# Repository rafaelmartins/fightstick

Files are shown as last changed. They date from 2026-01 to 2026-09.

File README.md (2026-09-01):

<!-- github-to-forgejo:notice:start -->
> [!IMPORTANT]
> Development has moved to [https://git.rafaelmartins.com/rafaelmartins/fightstick](https://git.rafaelmartins.com/rafaelmartins/fightstick). Please check [https://git.rafaelmartins.com/](https://git.rafaelmartins.com/) for details on how to contribute.
<!-- github-to-forgejo:notice:end -->

# fightstick

An open-source USB fight stick built around the [stm32f0-usbd-devboard](@@/p/stm32-usbd-devboards/stm32f0/), with a 3D-printable enclosure and arcade-grade controls.

For documentation please visit: https://rafaelmartins.com/p/fightstick/

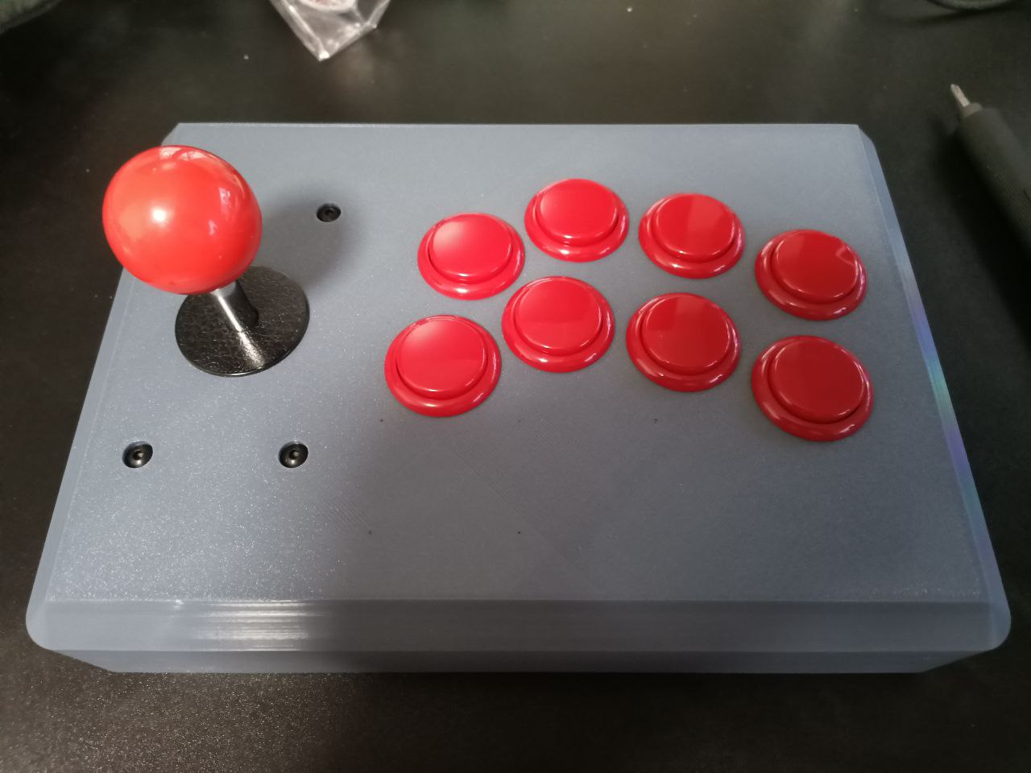
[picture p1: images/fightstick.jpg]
fightstick


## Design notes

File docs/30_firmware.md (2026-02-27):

# Firmware

The fightstick firmware is a bare-metal C application targeting the STM32F042K4 microcontroller on the [stm32f0-usbd-devboard](@@/p/stm32-usbd-devboards/stm32f0/). It implements a USB HID gamepad with a 2-axis digital joystick and 12 buttons. The firmware uses no HAL or RTOS -- it directly accesses peripheral registers via CMSIS headers and relies on the [usbd-fs-stm32](@@/p/usbd-fs-stm32/) library for USB device functionality.

## Building from source

### Prerequisites

- CMake 3.25 or later
- ARM GNU Toolchain (`arm-none-eabi`)
- Ninja (recommended) or Make

The following dependencies are fetched automatically via CMake FetchContent:

- [cmake-cmsis-stm32](@@/p/cmake-cmsis-stm32/) -- CMake build support for STM32 CMSIS-based projects
- [usbd-fs-stm32](@@/p/usbd-fs-stm32/) -- USB full-speed device library for STM32 microcontrollers

### Configure and build

```bash
cmake -B build -DCMAKE_BUILD_TYPE=Release -G Ninja
cmake --build build
```

### Output artifacts

The build produces the following in the `build/` directory:

| File | Description |
|---|---|
| `fightstick.elf` | ELF binary |
| `fightstick.elf.map` | Linker map |
| `fightstick.bin` | Raw binary |
| `fightstick.hex` | Intel HEX |
| `fightstick.dfu` | DFU with suffix (for `dfu-util`) |

### Memory layout

| Region | Start address | Size |
|---|---|---|
| Flash | `0x08000000` | 16 KB |
| RAM | `0x20000000` | 6 KB |

## Flashing

### Using USB DFU

Automated builds from the latest source are available from the [`rolling` release](https://github.com/rafaelmartins/fightstick/releases/tag/rolling).

The STM32F042K4 has a built-in USB DFU bootloader in system memory. There are two ways to enter DFU mode:

- **Empty MCU** -- a new, unprogrammed STM32F042K4 boots directly into its system memory DFU bootloader, so it is ready to flash immediately
- **Button combination** -- hold BTN09 (pin 18, B0) and BTN10 (pin 19, B1) simultaneously while powering on or resetting the device

When the firmware detects both BTN09 and BTN10 held at startup, it writes a magic value (`0xdeadbeef`) to an RTC backup register and triggers a software reset. On the subsequent boot, the firmware reads this value and jumps to the system bootloader at `0x1FFFC400`.

See the [Hardware Build Manual](@@/hardware/build-manual/) for general DFU flashing instructions using `dfu-util`.

### Using ST-Link

Flash via the provided CMake target:

```bash
cmake --build build --target fightstick-stlink-write
```

See the [Hardware Build Manual](@@/hardware/build-manual/) for general ST-Link setup and flashing instructions.

## Architecture overview

### Clock configuration

The firmware configures the system clock to use the HSI48 internal oscillator directly at 48 MHz with no PLL. Both AHB and APB buses run at 48 MHz (prescaler /1). One flash wait state is enabled as required for 48 MHz operation.

### Peripheral map

| Peripheral | Function |
|---|---|
| GPIOA PA0--PA9 | Button inputs (BTN01--BTN08, BTN11, BTN12) with internal pull-ups |
| GPIOA PA15 | Status LED output (active high) |
| GPIOB PB0--PB1 | Button inputs (BTN09, BTN10) with internal pull-ups |
| GPIOB PB3--PB6 | Joystick direction inputs (LEFT, RIGHT, DOWN, UP) with internal pull-ups |
| TIM17 | HID idle rate timer (one-pulse mode) |
| USB | Full-speed USB device peripheral |
| RTC BKP0R | Bootloader entry flag register |

See [Assembly](10_assembly.md) for physical wiring details and pin assignments.

### Main loop

The `main()` function initializes GPIO ports with pull-ups, checks for the DFU button combination, then configures the clock, idle timer, and USB peripheral. The main loop calls `usbd_task()` continuously to process USB events.

On each USB IN token for endpoint 1, the `usbd_in_cb()` callback reads all 16 GPIO inputs and constructs the HID report. The report is only sent when the input state changes or when the HID idle timer expires, reducing unnecessary USB traffic.

### Source files

| File | Purpose |
|---|---|
| `main.c` | GPIO initialization, clock setup, USB callbacks, input polling, and main loop |
| `descriptors.c` | USB device, configuration, interface, HID, and endpoint descriptors; HID report descriptor; string descriptors |
| `bootloader.c` | DFU bootloader entry logic using RTC backup register and system memory jump |
| `idle.c` | HID idle rate implementation using TIM17 in one-pulse mode |

## USB HID protocol

### Device identity

| Field | Value |
|---|---|
| USB version | 2.0 Full-Speed |
| Device class | HID (interface-level) |
| VID | `0x1d50` |
| PID | `0x619a` |
| Manufacturer | rgm.io |
| Product | fightstick |
| Serial number | STM32 internal unique ID |
| Max power | 40 mA (bus-powered) |
| HID version | 1.11 |

### Endpoints

| Direction | Type | Max packet size | Interval |
|---|---|---|---|
| EP1 IN | Interrupt | 64 bytes | 1 ms |

### HID report descriptor

The device uses the Generic Desktop / Gamepad usage page with a single input report.

| Report ID | Kind | Size | Description |
|---|---|---|---|
| 1 | Input | 2 bytes (+ 1 byte report ID) | Joystick axes and buttons |

Report layout (3 bytes total):

| Byte | Bits | Field | Values |
|---|---|---|---|
| 0 | 7:0 | Report ID | Always `0x01` |
| 1 | 1:0 | X axis | -1 (left), 0 (center), 1 (right) |
| 1 | 3:2 | Y axis | -1 (up), 0 (center), 1 (down) |
| 1 | 4 | Button 1 | 0 = released, 1 = pressed |
| 1 | 5 | Button 2 | 0 = released, 1 = pressed |
| 1 | 6 | Button 3 | 0 = released, 1 = pressed |
| 1 | 7 | Button 4 | 0 = released, 1 = pressed |
| 2 | 0 | Button 5 | 0 = released, 1 = pressed |
| 2 | 1 | Button 6 | 0 = released, 1 = pressed |
| 2 | 2 | Button 7 | 0 = released, 1 = pressed |
| 2 | 3 | Button 8 | 0 = released, 1 = pressed |
| 2 | 4 | Button 9 | 0 = released, 1 = pressed |
| 2 | 5 | Button 10 | 0 = released, 1 = pressed |
| 2 | 6 | Button 11 | 0 = released, 1 = pressed |
| 2 | 7 | Button 12 | 0 = released, 1 = pressed |

### Idle rate

The firmware implements HID Set_Idle and Get_Idle requests. The default idle rate is 500 ms (idle value 125). When the idle rate is non-zero, the firmware sends the current report periodically even if no input state has changed. When set to 0, reports are only sent on input changes.

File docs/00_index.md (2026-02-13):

---
menu: Main
---
**An open-source USB fight stick built around the [stm32f0-usbd-devboard](@@/p/stm32-usbd-devboards/stm32f0/), with a 3D-printable enclosure and arcade-grade controls.**

fightstick, assembled
The assembled fight stick, with a Sanwa JLF joystick and 30mm snap-in buttons

## Overview

fightstick is a USB gamepad designed for fighting games on Linux and MiSTer FPGA. It uses a [stm32f0-usbd-devboard](@@/p/stm32-usbd-devboards/stm32f0/) as its controller, a Sanwa JLF-TP-8YT joystick lever for directional input, eight Sanwa OBSF-30 game buttons, and four Sanwa OBSF-24 control buttons. The enclosure is fully 3D-printable.

The firmware is bare-metal C targeting the STM32F042K4 microcontroller, running at 48 MHz from the internal HSI48 oscillator. It presents itself as a standard USB HID gamepad with a 1 ms polling interval, requiring no custom drivers.

## Key highlights

- **Standard USB HID gamepad** -- no drivers required, works out of the box on Linux and MiSTer FPGA
- **1 ms polling interval** -- tested at 1.39 ms average button latency with a [Gamepad Latency Tester](https://gamepadla.com)
- **Sanwa arcade parts** -- JLF-TP-8YT joystick lever, OBSF-30 game buttons, and OBSF-24 control buttons
- **3D-printable enclosure** -- OpenSCAD parametric models for the panel and base plate
- **USB DFU firmware updates** -- enter DFU mode by pressing two buttons at startup, or flash via ST-Link
- **Bare-metal firmware** -- no HAL, no RTOS, built with [cmake-cmsis-stm32](@@/p/cmake-cmsis-stm32/) and [usbd-fs-stm32](@@/p/usbd-fs-stm32/)
- **Open source** -- hardware licensed under CERN-OHL-S-2.0, firmware under BSD-3-Clause

## How it works

The [stm32f0-usbd-devboard](@@/p/stm32-usbd-devboards/stm32f0/) reads 16 GPIO inputs (4 joystick directions and 12 buttons) using internal pull-up resistors. Each button and joystick microswitch connects its corresponding GPIO pin to ground. The firmware runs a USB HID interrupt IN endpoint that sends a 3-byte report containing a 2-axis digital joystick (X/Y values of -1, 0, or 1) and 12 button states at up to 1000 Hz. An on-board LED indicates USB enumeration status.

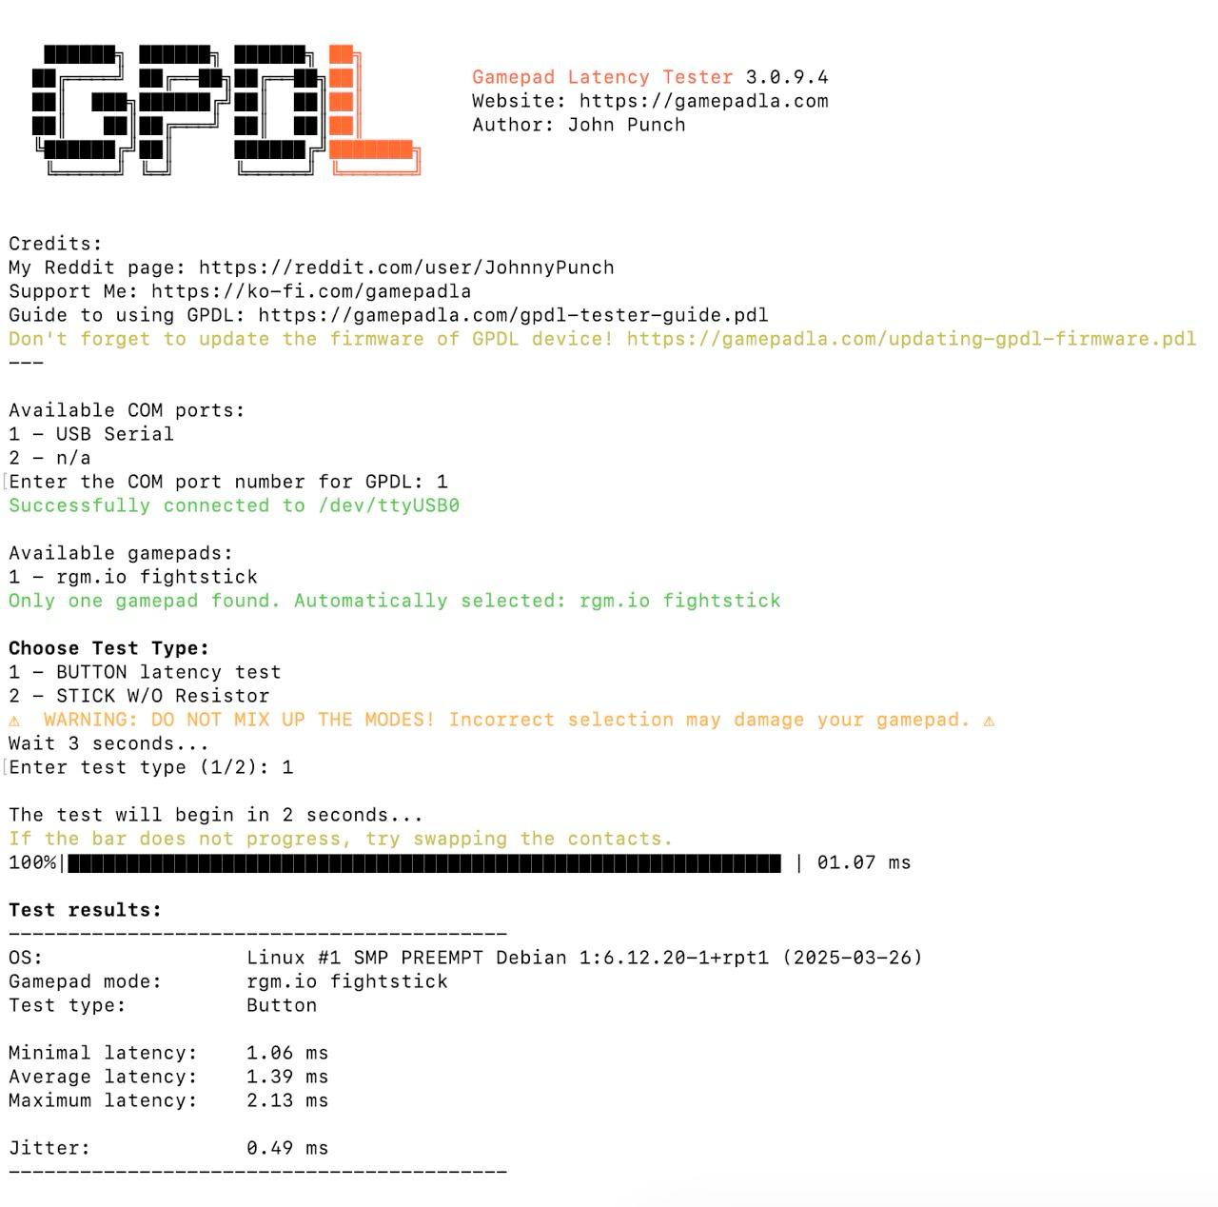
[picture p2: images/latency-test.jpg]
Gamepad Latency Tester results

Gamepad Latency Tester results: 1.06 ms minimum, 1.39 ms average, 2.13 ms maximum, 0.49 ms jitter

## Explore further

- [Assembly](10_assembly.md) -- parts list, wiring, and 3D-printed enclosure
- [Firmware](30_firmware.md) -- building, flashing, architecture, and USB HID protocol
- [Source code](https://github.com/rafaelmartins/fightstick) -- GitHub repository
- [stm32f0-usbd-devboard](@@/p/stm32-usbd-devboards/stm32f0/) -- development board documentation

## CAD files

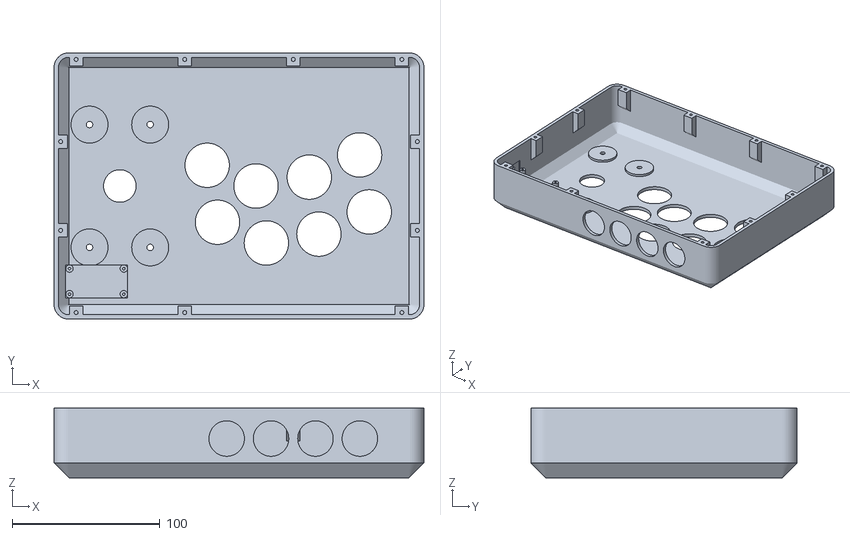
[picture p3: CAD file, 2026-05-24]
3d-models/panel.stl
250.0 x 180.0 x 47.0

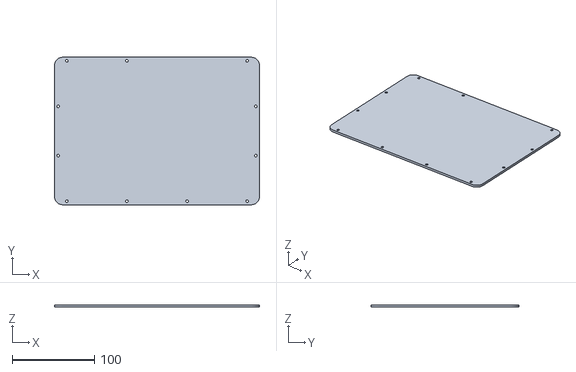
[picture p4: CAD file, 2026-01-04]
3d-models/base.stl
250.0 x 180.0 x 3.00

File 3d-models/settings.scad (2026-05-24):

/*
 * SPDX-FileCopyrightText: 2026 Rafael G. Martins <rafael@rafaelmartins.eng.br>
 * SPDX-License-Identifier: CERN-OHL-S-2.0
 */

button_control_count = 4;

length = 250;
width = 180;
height = 50;

thickness = 3;

panel_cut = 10;

button_control_d = 24;
button_control_distance = 30;
button_game_d = 30;

joystick_hole_d = 22;
joystick_width = 53;
joystick_length = 95;
joystick_width_screw_d = 41;
joystick_length_screw_d = 83;

joystick_x0 = 18 + joystick_width / 2;
joystick_y0 = width / 2;

joystick_screw_head_h = 2.8;
joystick_screw_head_d = 7.8;
joystick_screw_d = 4;
joystick_screw_base_h = 2;
joystick_screw_base_d = 25;

base_screw_padding_x = 15;
base_screw_padding_y = 60;
base_screw_dim = 9;
base_screw_d = 3;
base_screw_h = 16;
base_length_screw_distance = (length - 30) / 3;
base_width_screw_distance = (width - 120);

led_d = 3.2;
usb_height = 4.4;
usb_width = 8.2;

usb_cutout_padding_x = 1.6;
usb_cutout_padding_y = 12;
usb_cutout_padding_z = 18;
usb_cutout_thickness = thickness - 1.6;
usb_cutout_length = 28;
usb_cutout_height = 14;

devboard_pcb_height = 1.6;
devboard_width = 23.114;
devboard_length = 51.943;
devboard_screw_padding_front_x = 7.874;
devboard_screw_padding_back_x = 7.366;
devboard_screw_padding_y = 2.921;
devboard_screw_distance_y = 2 * 8.636;
devboard_screw_distance_x = 36.703;
devboard_screw_base_d = 5;
devboard_screw_base_h = height / 2;
devboard_screw_d = 2;
devboard_distance_usb = devboard_screw_padding_y + 8.636;
devboard_distance_led = devboard_screw_padding_y + 1.524;
devboard_pcb_padding_x = 2.6;
devboard_pcb_padding_y = 14;
devboard_base_distance_x = panel_cut - 2.1;
devboard_base_distance_y = usb_cutout_padding_y + 2.4;
devboard_base_length = devboard_screw_distance_x + 5.1;
devboard_base_width = usb_cutout_length - 5.7;
devboard_base_height = usb_cutout_padding_z - thickness;

$fn=50;

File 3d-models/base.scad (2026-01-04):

/*
 * SPDX-FileCopyrightText: 2026 Rafael G. Martins <rafael@rafaelmartins.eng.br>
 * SPDX-License-Identifier: CERN-OHL-S-2.0
 */

include <settings.scad>


translate([0, width, thickness]) rotate([180, 0, 0]) difference() {
    minkowski() {
        translate([panel_cut, panel_cut, 0])
            cube([length - 2 * panel_cut, width - 2 * panel_cut, thickness - 1]);
        cylinder(r=panel_cut, h=1);
    }

    for (i=[0:3])
        if (i != 2)
            translate([base_screw_padding_x + i * base_length_screw_distance, base_screw_dim / 2, 0])
                cylinder(h=thickness, d=base_screw_d * 1.1);

    for (i=[0:3])
        translate([base_screw_padding_x + i * base_length_screw_distance, width - base_screw_dim / 2, 0])
            cylinder(h=thickness, d=base_screw_d * 1.1);

    for (i=[0:1])
         translate([base_screw_dim / 2, base_screw_padding_y + i * base_width_screw_distance, 0])
             cylinder(h=thickness, d=base_screw_d * 1.1);

    for (i=[0:1])
         translate([length - base_screw_dim / 2, base_screw_padding_y + i * base_width_screw_distance, 0])
             cylinder(h=thickness, d=base_screw_d * 1.1);
}

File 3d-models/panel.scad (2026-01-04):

/*
 * SPDX-FileCopyrightText: 2026 Rafael G. Martins <rafael@rafaelmartins.eng.br>
 * SPDX-License-Identifier: CERN-OHL-S-2.0
 */

include <lib/screw-base.scad>
include <settings.scad>


difference() {
    union() {
        difference() {
            minkowski() {
                translate([panel_cut, panel_cut, 0])
                    cube([length - 2 * panel_cut, width - 2 * panel_cut, height - thickness - panel_cut]);
                cylinder(r1=0, r2=panel_cut, h=panel_cut);
            }

            translate([0, 0, thickness])
                minkowski() {
                    translate([panel_cut, panel_cut, 0])
                        cube([length - 2 * panel_cut, width - 2 * panel_cut, height - thickness - panel_cut]);
                    cylinder(r1=0, r2=panel_cut - thickness, h=panel_cut - thickness);
                }
        }

        translate([joystick_x0, joystick_y0, 0]) {
            translate([-joystick_width_screw_d / 2, -joystick_length_screw_d / 2, 0])
                cylinder(h=thickness + joystick_screw_base_h, d=joystick_screw_base_d);
            translate([-joystick_width_screw_d / 2, joystick_length_screw_d / 2, 0])
                cylinder(h=thickness + joystick_screw_base_h, d=joystick_screw_base_d);
            translate([joystick_width_screw_d / 2, -joystick_length_screw_d / 2, 0])
                cylinder(h=thickness + joystick_screw_base_h, d=joystick_screw_base_d);
            translate([joystick_width_screw_d / 2, joystick_length_screw_d / 2, 0])
                cylinder(h=thickness + joystick_screw_base_h, d=joystick_screw_base_d);
        }

        for (i=[0:3])
            if (i != 2)
                translate([base_screw_padding_x + i * base_length_screw_distance, base_screw_dim / 2, height - thickness])
                    rotate([0, 0, 90])
                        screw_base(dim=base_screw_dim, screw_d=base_screw_d, screw_h=base_screw_h);

        for (i=[0:3])
            translate([base_screw_padding_x + i * base_length_screw_distance, width - base_screw_dim / 2, height - thickness])
                rotate([0, 0, -90])
                    screw_base(dim=base_screw_dim, screw_d=base_screw_d, screw_h=base_screw_h);

        for (i=[0:1])
             translate([base_screw_dim / 2, base_screw_padding_y + i * base_width_screw_distance, height - thickness])
                 screw_base(dim=base_screw_dim, screw_d=base_screw_d, screw_h=base_screw_h);

        for (i=[0:1])
             translate([length - base_screw_dim / 2, base_screw_padding_y + i * base_width_screw_distance, height - thickness])
                 rotate([0, 0, 180])
                     screw_base(dim=base_screw_dim, screw_d=base_screw_d, screw_h=base_screw_h);

        for (i=[0:1])
            for (j=[0:1])
                translate([devboard_pcb_padding_x + devboard_screw_padding_front_x + i * devboard_screw_distance_x,
                           devboard_pcb_padding_y + devboard_screw_padding_y + j * devboard_screw_distance_y,
                           thickness])
                    cylinder(h=devboard_screw_base_h, d=devboard_screw_base_d);

        translate([devboard_base_distance_x, devboard_base_distance_y, thickness])
            cube([devboard_base_length, devboard_base_width, devboard_base_height]);
    }

    for (i=[0:1])
        for (j=[0:1])
            translate([devboard_pcb_padding_x + devboard_screw_padding_front_x + i * devboard_screw_distance_x,
                       devboard_pcb_padding_y + devboard_screw_padding_y + j * devboard_screw_distance_y,
                       thickness])
                cylinder(h=devboard_screw_base_h, d=devboard_screw_d * 0.9);

    translate([0, devboard_pcb_padding_y + devboard_width - devboard_distance_usb - usb_width / 2,
               thickness + devboard_screw_base_h - usb_height + 0.2])
        cube([thickness, usb_width, usb_height]);

    translate([0, devboard_pcb_padding_y + devboard_width - devboard_distance_led,
               thickness + devboard_screw_base_h - led_d / 2])
        rotate([-90, 0, -90])
            cylinder(h=thickness, d=led_d);

    translate([base_screw_padding_x + base_length_screw_distance, 0, 3 + (height - thickness) / 2])
        for (i=[0:button_control_count - 1])
            translate([(2 * base_length_screw_distance - (button_control_count - 1) * button_control_distance) / 2 +
                       i * button_control_distance, 0, 0])
                rotate([-90, 0, 0])
                    cylinder(h=thickness + 0.1, d=button_control_d);

    translate([joystick_x0, joystick_y0, 0]) {
        cylinder(h=thickness, d=joystick_hole_d);

        translate([-joystick_width_screw_d / 2, -joystick_length_screw_d / 2, 0]) {
            cylinder(h=joystick_screw_head_h, d=joystick_screw_head_d);
            cylinder(h=thickness + joystick_screw_base_h, d=joystick_screw_d * 1.1);
        }
        translate([-joystick_width_screw_d / 2, joystick_length_screw_d / 2, 0]) {
            cylinder(h=joystick_screw_head_h, d=joystick_screw_head_d);
            cylinder(h=thickness + joystick_screw_base_h, d=joystick_screw_d * 1.1);
        }
        translate([joystick_width_screw_d / 2, -joystick_length_screw_d / 2, 0]) {
            cylinder(h=joystick_screw_head_h, d=joystick_screw_head_d);
            cylinder(h=thickness + joystick_screw_base_h, d=joystick_screw_d * 1.1);
        }
        translate([joystick_width_screw_d / 2, joystick_length_screw_d / 2, 0]) {
            cylinder(h=joystick_screw_head_h, d=joystick_screw_head_d);
            cylinder(h=thickness + joystick_screw_base_h, d=joystick_screw_d * 1.1);
        }

        translate([59, 14, 0]) {
            cylinder(h=thickness, d=button_game_d);
            translate([7, -38.5, 0])
                cylinder(h=thickness, d=button_game_d);
            translate([33, -14, 0]) {
                cylinder(h=thickness, d=button_game_d);
                translate([7, -38.5, 0])
                    cylinder(h=thickness, d=button_game_d);
                translate([36, 6, 0]) {
                    cylinder(h=thickness, d=button_game_d);
                    translate([6.5, -38.5, 0])
                        cylinder(h=thickness, d=button_game_d);
                    translate([34, 15, 0]) {
                        cylinder(h=thickness, d=button_game_d);
                        translate([6.5, -38.5, 0])
                            cylinder(h=thickness, d=button_game_d);
                    }
                }
            }
        }
    }

    translate([usb_cutout_padding_x, usb_cutout_padding_y, usb_cutout_padding_z])
        cube([usb_cutout_thickness, usb_cutout_length, usb_cutout_height]);
}

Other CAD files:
3d-models/test.scad

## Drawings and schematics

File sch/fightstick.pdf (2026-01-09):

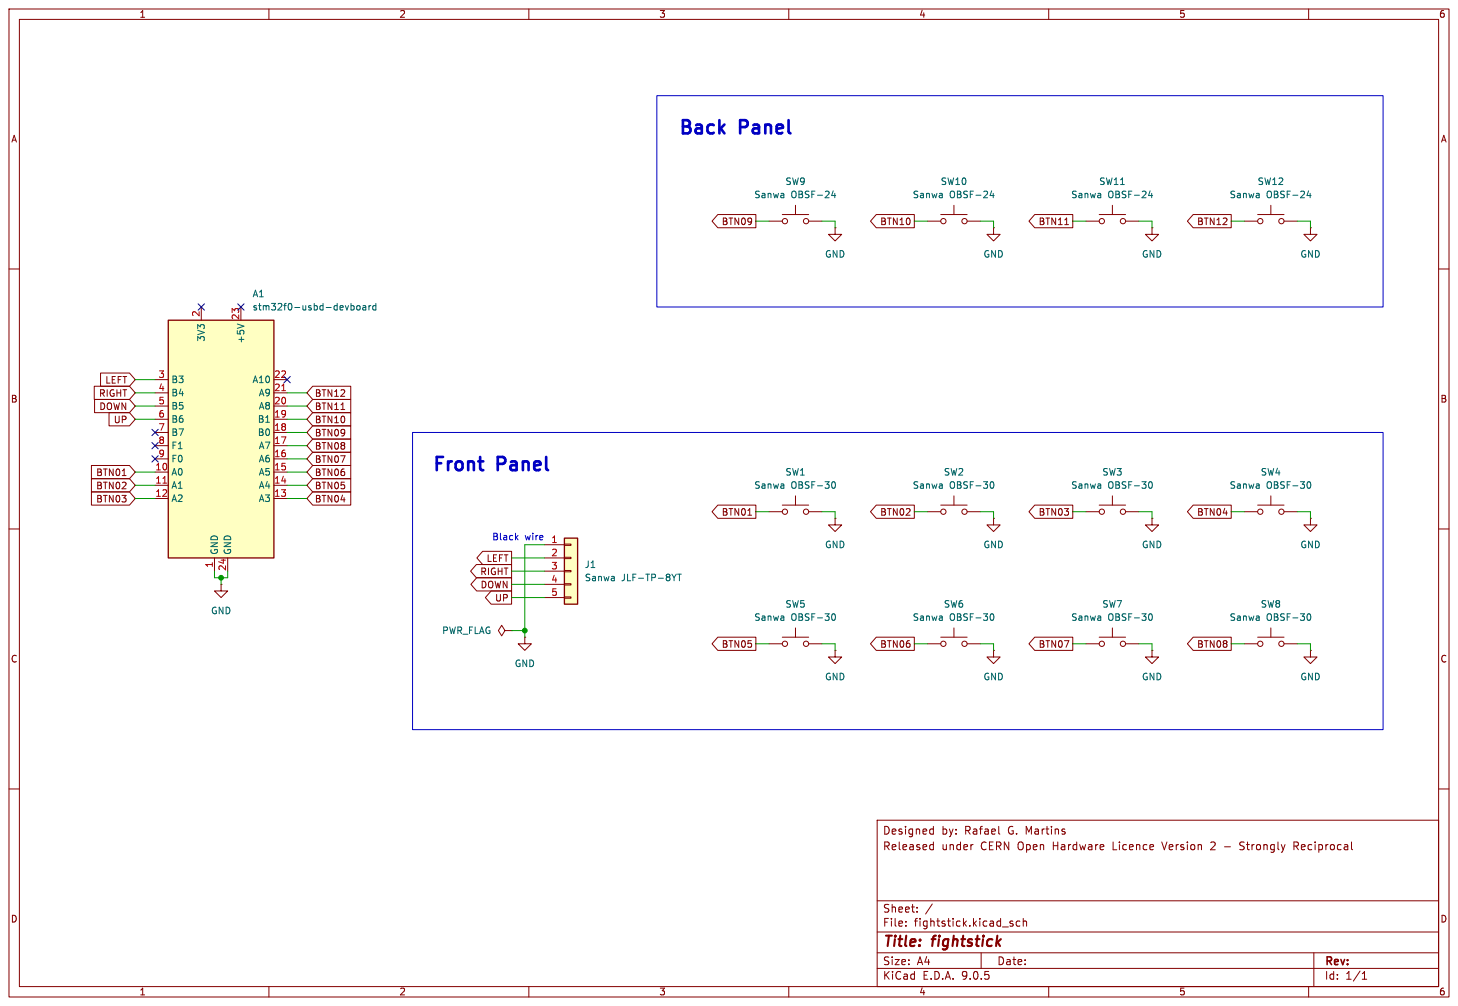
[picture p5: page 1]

Back Panel
SW12 Sanwa OBSF-24 SW7 Sanwa OBSF-30GND

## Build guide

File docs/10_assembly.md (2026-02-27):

# Assembly

The fightstick consists of a 3D-printed enclosure, Sanwa arcade components, and a [stm32f0-usbd-devboard](@@/p/stm32-usbd-devboards/stm32f0/) connected via point-to-point wiring. All buttons and the joystick microswitches connect to GPIO pins using the internal pull-up resistors of the STM32F042K4 -- no external resistors or additional circuitry is needed.

fightstick, assembled
The assembled fight stick

## Parts list

| Part | Quantity | Description |
|---|---|---|
| [stm32f0-usbd-devboard](@@/p/stm32-usbd-devboards/stm32f0/) | 1 | STM32F042K4-based USB development board |
| Sanwa JLF-TP-8YT | 1 | Joystick lever with 5-pin wiring harness |
| Sanwa OBSF-30 | 8 | 30 mm pushbuttons (game buttons) |
| Sanwa OBSF-24 | 4 | 24 mm pushbuttons (control buttons) |
| M4 screws with nuts | 4 | Joystick mounting screws |
| M3 self-tapping screws | 11 | Enclosure base plate screws |
| M2 self-tapping screws | 4 | Development board mounting screws |

## Wiring

Each button and joystick microswitch connects between the corresponding devboard GPIO pin and GND. All GPIO inputs use the MCU's internal pull-up resistors, so no external pull-ups are needed. When a button is pressed, it pulls the pin to ground.

### Devboard pin assignments

```
                          DEVBOARD
                +--------------------------+
                |          +----+          |
                |          |USB |          |
                |          +----+          |
  GND <---------| 1  (GND)       (GND)  24 |---------> GND
                | 2  (3V3)       (+5V)  23 |
 LEFT <---------| 3  (B3)        (A10)  22 |
RIGHT <---------| 4  (B4)         (A9)  21 |---------> BTN12
 DOWN <---------| 5  (B5)         (A8)  20 |---------> BTN11
   UP <---------| 6  (B6)         (B1)  19 |---------> BTN10
                | 7  (B7)         (B0)  18 |---------> BTN09
                | 8  (F1)         (A7)  17 |---------> BTN08
                | 9  (F0)         (A6)  16 |---------> BTN07
BTN01 <---------| 10 (A0)         (A5)  15 |---------> BTN06
BTN02 <---------| 11 (A1)         (A4)  14 |---------> BTN05
BTN03 <---------| 12 (A2)         (A3)  13 |---------> BTN04
                +--------------------------+
```

> [!NOTE]
> Pins 7 (B7), 8 (F1), 9 (F0), and 22 (A10) are unused.

> [!WARNING]
> Pin 2 (3V3) and pin 23 (+5V) are power outputs and must not be connected to button inputs.

### Joystick wiring

The Sanwa JLF-TP-8YT comes with a 5-pin wiring harness. Connect the joystick harness to the devboard as follows:

| Joystick signal | Devboard pin |
|---|---|
| LEFT | Pin 3 (B3) |
| RIGHT | Pin 4 (B4) |
| DOWN | Pin 5 (B5) |
| UP | Pin 6 (B6) |
| GND (black wire) | Pin 1 or 24 (GND) |

### Game buttons (OBSF-30)

The eight 30 mm game buttons are arranged in a staggered layout on the panel. Each button has two terminals: connect one terminal to the corresponding GPIO pin and the other to GND.

| Button | Devboard pin |
|---|---|
| BTN01 | Pin 10 (A0) |
| BTN02 | Pin 11 (A1) |
| BTN03 | Pin 12 (A2) |
| BTN04 | Pin 13 (A3) |
| BTN05 | Pin 14 (A4) |
| BTN06 | Pin 15 (A5) |
| BTN07 | Pin 16 (A6) |
| BTN08 | Pin 17 (A7) |

### Control buttons (OBSF-24)

The four 24 mm control buttons are mounted on the back face of the enclosure. Each button connects the same way as the game buttons.

| Button | Devboard pin |
|---|---|
| BTN09 | Pin 18 (B0) |
| BTN10 | Pin 19 (B1) |
| BTN11 | Pin 20 (A8) |
| BTN12 | Pin 21 (A9) |

> [!NOTE]
> BTN09 and BTN10 have a special function: holding both at power-on enters USB DFU mode for firmware updates. See [Firmware](30_firmware.md) for details.

## 3D-printed enclosure

The enclosure is a two-part design modeled in OpenSCAD: a panel (top shell with button/joystick cutouts) and a flat base plate. The source files are in the `3d-models/` directory.

| File | Description |
|---|---|
| `panel.scad` | Top shell with joystick mounting, button holes, USB cutout, and screw bases |
| `base.scad` | Flat base plate with screw holes |
| `settings.scad` | Shared dimensions and parameters |

The enclosure dimensions are 250 mm x 180 mm x 50 mm with 3 mm wall thickness. The panel includes:

- 1x 22 mm joystick shaft hole with 4x M4 mounting posts
- 8x 30 mm game button holes in a staggered fighting game layout
- 4x 24 mm control button holes on the back face
- A USB connector cutout on the left side wall
- A 3.2 mm LED hole on the left side wall
- M2 screw standoffs for the development board
- M3 screw bases for the base plate

Pre-generated STL files (`panel.stl` and `base.stl`) are included in the repository.

## LED behavior

The development board's on-board LED (PA15) indicates USB enumeration status. It turns on when the device receives a USB address from the host and turns off on USB bus reset. No additional wiring is needed for the LED -- it is visible through a 3.2 mm hole in the left side wall of the enclosure.

## Firmware

After completing assembly, flash the firmware to the development board. See [Firmware](30_firmware.md) for build and flashing instructions.

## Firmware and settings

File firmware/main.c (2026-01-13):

// SPDX-FileCopyrightText: 2026 Rafael G. Martins <rafael@rafaelmartins.eng.br>
// SPDX-License-Identifier: BSD-3-Clause

#include <assert.h>
#include <stdlib.h>

#include <stm32f0xx.h>

#include <usbd.h>
#include <usb-std-hid.h>

#include "bootloader.h"
#include "idle.h"

static uint32_t sreport = 0;
static union {
    struct __attribute__((packed)) {
        uint8_t id;
        int8_t x : 2;
        int8_t y : 2;
        bool btn01 : 1;
        bool btn02 : 1;
        bool btn03 : 1;
        bool btn04 : 1;
        bool btn05 : 1;
        bool btn06 : 1;
        bool btn07 : 1;
        bool btn08 : 1;
        bool btn09 : 1;
        bool btn10 : 1;
        bool btn11 : 1;
        bool btn12 : 1;
    } s;
    uint32_t r;
} report = {
    .s.id = 1,
};
static_assert(sizeof(report.s) == 3);


void
clock_init(void)
{
    // 1 flash wait cycle required to operate @ 48MHz (RM0091 section 3.5.1)
    FLASH->ACR &= ~FLASH_ACR_LATENCY;
    FLASH->ACR |= FLASH_ACR_LATENCY;
    while ((FLASH->ACR & FLASH_ACR_LATENCY) != FLASH_ACR_LATENCY);

    RCC->CR2 |= RCC_CR2_HSI48ON;
    while ((RCC->CR2 & RCC_CR2_HSI48RDY) != RCC_CR2_HSI48RDY);

    RCC->CFGR &= ~(RCC_CFGR_HPRE | RCC_CFGR_PPRE | RCC_CFGR_SW);
    RCC->CFGR |= RCC_CFGR_HPRE_DIV1 | RCC_CFGR_PPRE_DIV1 | RCC_CFGR_SW_HSI48;
    while((RCC->CFGR & RCC_CFGR_SWS) != RCC_CFGR_SWS_HSI48);

    SystemCoreClock = 48000000;
}


void
usbd_in_cb(uint8_t ept)
{
    if (ept != 1)
        return;

    // B3 - LEFT
    // B4 - RIGHT
    // B5 - DOWN
    // B6 - UP
    // A0 - BTN01
    // A1 - BTN02
    // A2 - BTN03
    // A3 - BTN04
    // A4 - BTN05
    // A5 - BTN06
    // A6 - BTN07
    // A7 - BTN08
    // B0 - BTN09
    // B1 - BTN10
    // A8 - BTN11
    // A9 - BTN12

    report.s.x = (GPIOB->IDR & GPIO_IDR_4) == 0 ? 1 : ((GPIOB->IDR & GPIO_IDR_3) == 0 ? -1 : 0);
    report.s.y = (GPIOB->IDR & GPIO_IDR_5) == 0 ? 1 : ((GPIOB->IDR & GPIO_IDR_6) == 0 ? -1 : 0);
    report.s.btn01 = (GPIOA->IDR & GPIO_IDR_0) == 0;
    report.s.btn02 = (GPIOA->IDR & GPIO_IDR_1) == 0;
    report.s.btn03 = (GPIOA->IDR & GPIO_IDR_2) == 0;
    report.s.btn04 = (GPIOA->IDR & GPIO_IDR_3) == 0;
    report.s.btn05 = (GPIOA->IDR & GPIO_IDR_4) == 0;
    report.s.btn06 = (GPIOA->IDR & GPIO_IDR_5) == 0;
    report.s.btn07 = (GPIOA->IDR & GPIO_IDR_6) == 0;
    report.s.btn08 = (GPIOA->IDR & GPIO_IDR_7) == 0;
    report.s.btn09 = (GPIOB->IDR & GPIO_IDR_0) == 0;
    report.s.btn10 = (GPIOB->IDR & GPIO_IDR_1) == 0;
    report.s.btn11 = (GPIOA->IDR & GPIO_IDR_8) == 0;
    report.s.btn12 = (GPIOA->IDR & GPIO_IDR_9) == 0;

    if (idle_request() || report.r != sreport) {
        sreport = report.r;
        usbd_in(ept, &report.s, sizeof(report.s));
    }
}


bool
usbd_ctrl_request_handle_class_cb(usb_ctrl_request_t *req)
{
    switch (req->bRequest) {
    case USB_REQ_HID_SET_IDLE:
        if (((req->bmRequestType & USB_REQ_DIR_MASK) == USB_REQ_DIR_DEVICE_TO_HOST) ||
            (req->wIndex != 0) ||
            ((((uint8_t) req->wValue) != 0) && (((uint8_t) req->wValue) != 1)))
            break;

        idle_set((uint8_t) (req->wValue >> 8));
        return true;

    case USB_REQ_HID_GET_IDLE:
        {
            if (((req->bmRequestType & USB_REQ_DIR_MASK) == USB_REQ_DIR_HOST_TO_DEVICE) ||
                (req->wIndex != 0) ||
                ((((uint8_t) req->wValue) != 0) && (((uint8_t) req->wValue) != 1)))
                break;

            uint8_t data = idle_get();
            usbd_control_in(&data, sizeof(data), req->wLength);
            return true;
        }
    }
    return false;
}


void
usbd_reset_hook_cb(bool before)
{
    if (!before)
        return;

    sreport = 0;
    GPIOA->BSRR = GPIO_BSRR_BR_15;
}


void
usbd_set_address_hook_cb(uint8_t addr)
{
    (void) addr;
    GPIOA->BSRR = GPIO_BSRR_BS_15;
}


int
main(void)
{
    bootloader_entry();

    RCC->AHBENR |= RCC_AHBENR_GPIOAEN | RCC_AHBENR_GPIOBEN;

    GPIOA->MODER &= ~GPIO_MODER_MODER15;
    GPIOA->MODER |= GPIO_MODER_MODER15_0;
    GPIOA->BSRR = GPIO_BSRR_BR_15;

    GPIOA->PUPDR |=
        GPIO_PUPDR_PUPDR0_0 | GPIO_PUPDR_PUPDR1_0 | GPIO_PUPDR_PUPDR2_0 |
        GPIO_PUPDR_PUPDR3_0 | GPIO_PUPDR_PUPDR4_0 | GPIO_PUPDR_PUPDR5_0 |
        GPIO_PUPDR_PUPDR6_0 | GPIO_PUPDR_PUPDR7_0 | GPIO_PUPDR_PUPDR8_0 |
        GPIO_PUPDR_PUPDR9_0;
    GPIOB->PUPDR |=
        GPIO_PUPDR_PUPDR0_0 | GPIO_PUPDR_PUPDR1_0 | GPIO_PUPDR_PUPDR3_0 |
        GPIO_PUPDR_PUPDR4_0 | GPIO_PUPDR_PUPDR5_0 | GPIO_PUPDR_PUPDR6_0;

    // wait a little bit until the pull-ups are stable.
    for (__IO uint16_t i = 0xffff; i; i--);

    if ((GPIOB->IDR & (GPIO_IDR_0 | GPIO_IDR_1)) == 0)
        bootloader_reset();

    clock_init();
    idle_init();
    usbd_init();

    while (true)
        usbd_task();

    return 0;
}

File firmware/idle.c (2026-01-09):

// SPDX-FileCopyrightText: 2026 Rafael G. Martins <rafael@rafaelmartins.eng.br>
// SPDX-License-Identifier: BSD-3-Clause

#include <stdbool.h>
#include <stdint.h>

#include <stm32f0xx.h>

#include "idle.h"

static uint8_t idle_val = 125;  // 500ms


void
idle_init(void)
{
    RCC->APB2ENR |= RCC_APB2ENR_TIM17EN;

    TIM17->CR1 = TIM_CR1_OPM | TIM_CR1_URS;
    TIM17->DIER = TIM_DIER_UIE;
    TIM17->PSC = SystemCoreClock / 1000 - 1;
}


void
idle_set(uint8_t val)
{
    idle_val = val;
}


uint8_t
idle_get(void)
{
    return idle_val;
}


bool
idle_request(void)
{
    if (idle_val == 0) {
        if ((TIM17->CR1 & TIM_CR1_CEN) == TIM_CR1_CEN)
            TIM17->CR1 &= ~TIM_CR1_CEN;
        return false;
    }

    if ((TIM17->SR & TIM_SR_UIF) == TIM_SR_UIF) {
        TIM17->SR &= ~TIM_SR_UIF;
        return true;
    }

    if ((TIM17->CR1 & TIM_CR1_CEN) != TIM_CR1_CEN) {
        TIM17->ARR = (((uint16_t) idle_val) << 2) - 1;
        TIM17->EGR = TIM_EGR_UG;
        TIM17->CR1 |= TIM_CR1_CEN;
    }
    return false;
}

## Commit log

2026-01-04 3d-models: initial implementation
    [base.scad, base.stl, panel.scad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]
2026-01-09 sch: initial design
    [fightstick.kicad_sch]
2026-01-11 firmware: update usb vid/pid to openmoko
2026-01-13 firmware: implement hid idle
    the hid class handler to set/get idle state was added before, but the timer was
    not initialized and the requests were not respecting the idle state.
2026-05-24 3d-models: fix devboard position
    [panel.stl, settings.scad]
